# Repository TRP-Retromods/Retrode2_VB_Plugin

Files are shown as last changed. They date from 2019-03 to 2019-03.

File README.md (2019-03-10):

# Retrode2 Virtual Boy Plugin
Virtual Boy plugin for the Retrode 2. Support RAM/ROM acces. Should be working with Hyper Fighting

Based on JonY and Skaman works. I've added a 74HC4053D and a switch to make it work with Hyper Fighting. It's working with classic VB Games (Rom/Save game) but unfortunately I can't test it with Hyper Fighting (because game was a limited run and is freaking expensive.

You'll find in the depository:
- The PCB (Eagle File and Gerber Files in a .ZIP) - Yes you need to print the small part on the top.
- The STL file of the cart sled. I recommand ABS or PETG for printing material.
- The PSD file for the label. Work well with decal paper

You'll need to assemble it:
- a 74HC4053D in SOIC package
- a SPDT switch https://www.digikey.ca/product-detail/en/c-k/OS102011MS2QN1/CKN9565-ND/411602
- a right angle 1.7mm spacing row male header. You have 2x60pins to populate. I used two https://www.digikey.ca/product-detail/en/M50-3905042/952-1704-ND/2762133 to make one cart slot.
- an empty genesis cart shell.

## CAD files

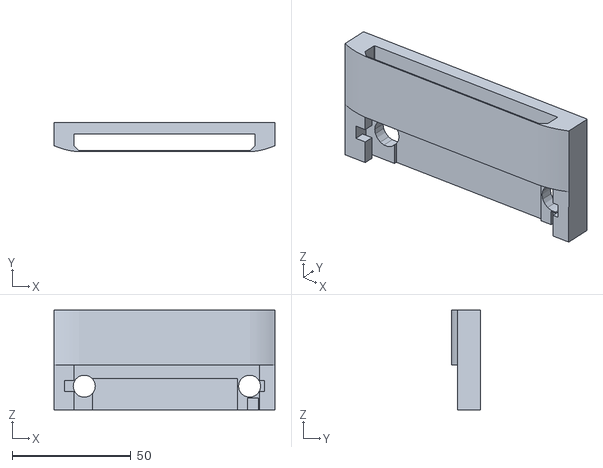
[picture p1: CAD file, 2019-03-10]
VB_CartSlot.STL
92.9 x 12.4 x 42.0

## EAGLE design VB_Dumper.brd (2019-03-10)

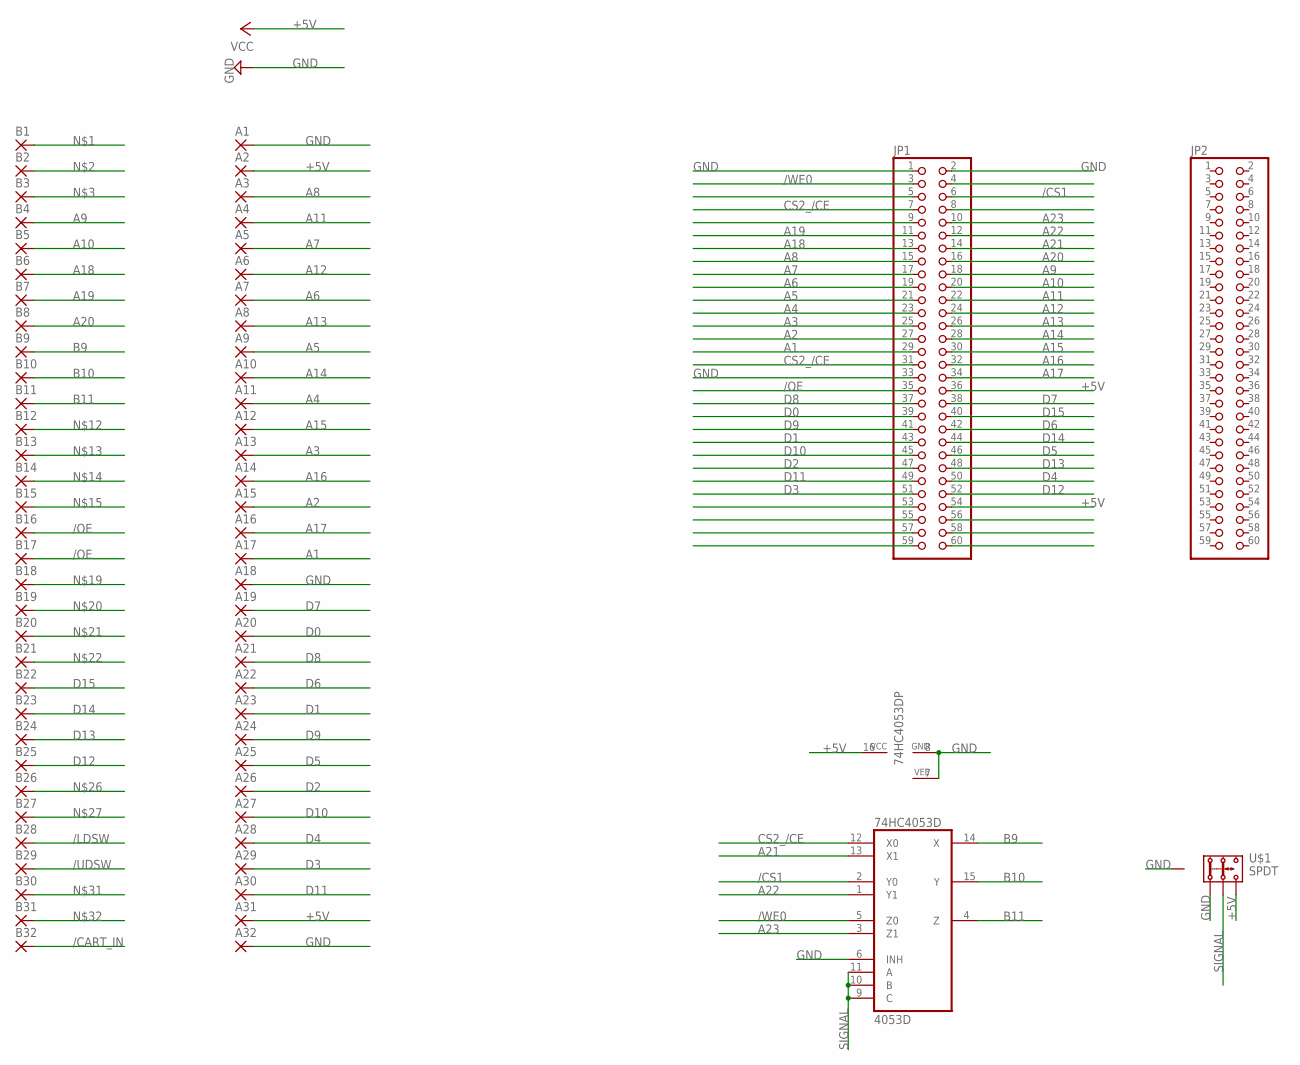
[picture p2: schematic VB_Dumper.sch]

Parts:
74HC4053D: 4053D; SO16
A1, A2, A3, A4, A5, A6, A7, A8, A9, A10, A11, A12, A13, A14, A15, A16, A17, A18, A19, A20, A21, A22, A23, A24, A25, A26, A27, A28, A29, A30, A31, A32: SMD2; SMD1,27-2,54
B1, B2, B3, B4, B5, B6, B7, B8, B9, B10, B11, B12, B13, B14, B15, B16, B17, B18, B19, B20, B21, B22, B23, B24, B25, B26, B27, B28, B29, B30, B31, B32: SMD2; SMD1,27-2,54
JP1, JP2: PINHD-2X30_2.00; 2X30M
U$1: SPDT

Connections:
+5V: 74HC4053D.16 (VCC), A2.1, A31.1, JP1.36, JP1.54, U$1.3.2
/CART_IN: B32.1
/CS1: 74HC4053D.2 (Y0), JP1.6
/LDSW: B28.1
/OE: B16.1, B17.1, JP1.35
/UDSW: B29.1
/WE0: 74HC4053D.5 (Z0), JP1.3
A1: A17.1, JP1.29
A2: A15.1, JP1.27
A3: A13.1, JP1.25
A4: A11.1, JP1.23
A5: A9.1, JP1.21
A6: A7.1, JP1.19
A7: A5.1, JP1.17
A8: A3.1, JP1.15
A9: B4.1, JP1.18
A10: B5.1, JP1.20
A11: A4.1, JP1.22
A12: A6.1, JP1.24
A13: A8.1, JP1.26
A14: A10.1, JP1.28
A15: A12.1, JP1.30
A16: A14.1, JP1.32
A17: A16.1, JP1.34
A18: B6.1, JP1.13
A19: B7.1, JP1.11
A20: B8.1, JP1.16
A21: 74HC4053D.13 (X1), JP1.14
A22: 74HC4053D.1 (Y1), JP1.12
A23: 74HC4053D.3 (Z1), JP1.10
B9: 74HC4053D.14 (X), B9.1
B10: 74HC4053D.15 (Y), B10.1
B11: 74HC4053D.4 (Z), B11.1
CS2_/CE: 74HC4053D.12 (X0), JP1.7, JP1.31
D0: A20.1, JP1.39
D1: A23.1, JP1.43
D2: A26.1, JP1.47
D3: A29.1, JP1.51
D4: A28.1, JP1.50
D5: A25.1, JP1.46
D6: A22.1, JP1.42
D7: A19.1, JP1.38
D8: A21.1, JP1.37
D9: A24.1, JP1.41
D10: A27.1, JP1.45
D11: A30.1, JP1.49
D12: B25.1, JP1.52
D13: B24.1, JP1.48
D14: B23.1, JP1.44
D15: B22.1, JP1.40
GND: 74HC4053D.6 (INH), 74HC4053D.7 (VEE), 74HC4053D.8 (GND), A1.1, A18.1, A32.1, JP1.1, JP1.2, JP1.33, U$1.1.2, U$1.P$1 (GND), U$1.P$2 (GND)
SIGNAL: 74HC4053D.9 (C), 74HC4053D.10 (B), 74HC4053D.11 (A), U$1.2.2

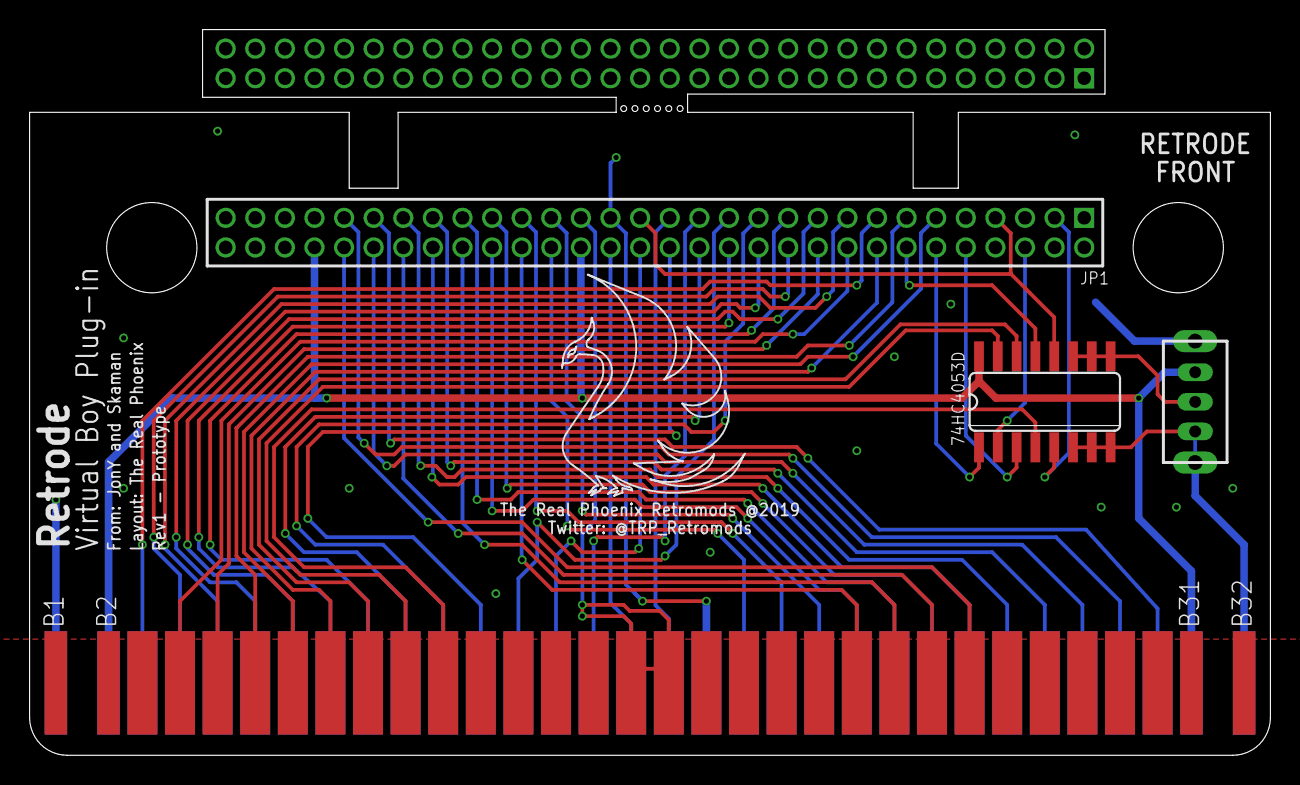
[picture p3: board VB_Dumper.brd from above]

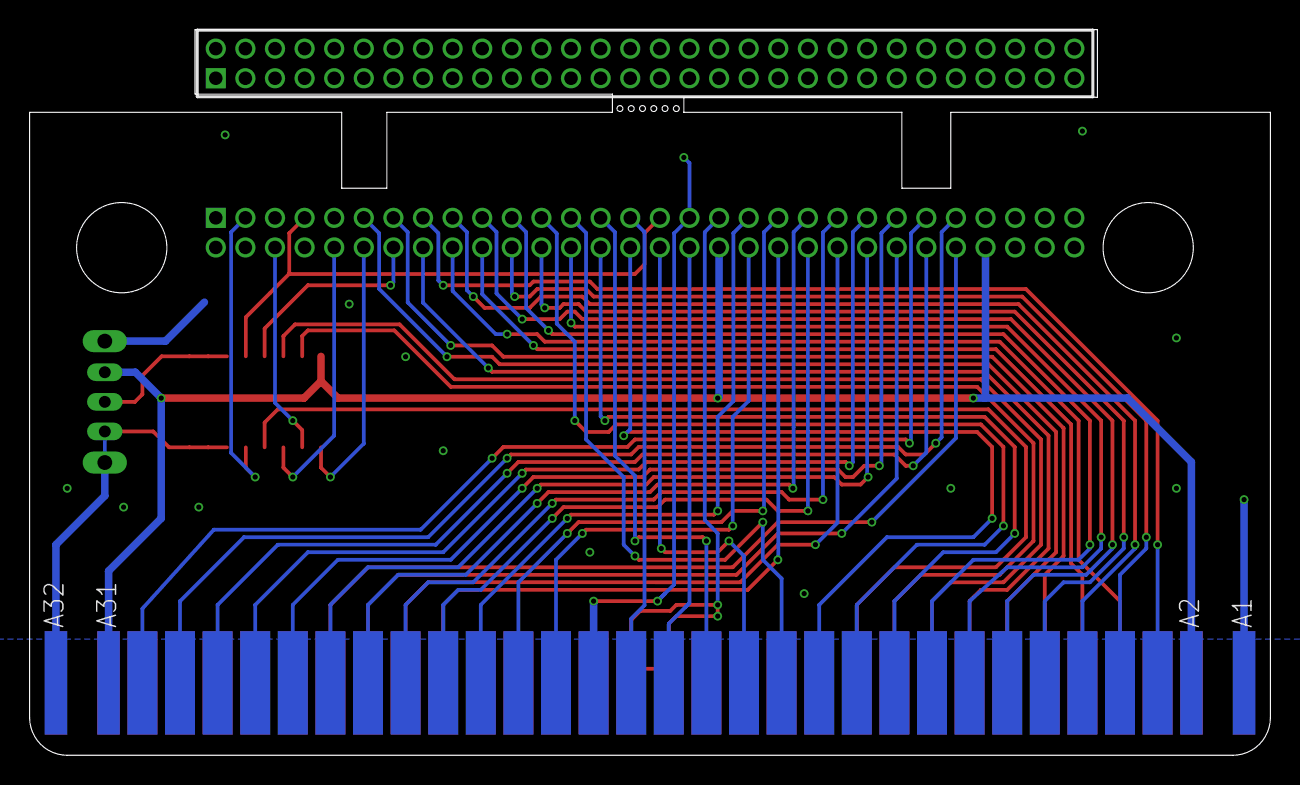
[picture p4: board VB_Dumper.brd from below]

Board: 2 copper layers, 83.8 x 49.0 mm, 69 parts (33 on the bottom side), 49 nets.

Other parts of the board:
U$2: LOGO

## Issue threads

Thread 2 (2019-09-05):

The provided STL files has some slicing issues

kperkins1982, 2019-09-05:
The STL file has some issues making it difficult to print.

The thin part in the front when sliced in prusa slicer creates a gap such that it doesn't connect properly.  If sliced in CURA where it connects to the main part is very thin and may snap off.

Do you by any chance have the original design files say .f3d if made in fusion360 so that I can modify this to be a bit thicker at the connection?
